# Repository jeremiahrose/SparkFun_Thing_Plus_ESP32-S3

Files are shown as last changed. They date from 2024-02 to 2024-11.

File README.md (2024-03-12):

SparkFun Thing Plus - ESP32-S3
========================================

SparkFun Thing Plus - ESP32-S3 (https://www.sparkfun.com/products/24408)

*[SparkFun Thing Plus - ESP32-S3) (WRL-24408)](https://www.sparkfun.com/products/24408)*

The [SparkFun Thing Plus - ESP32-S3](https://www.sparkfun.com/products/24408) brings a powerful and versatile IoT development platform to the Thing Plus product line. It features the ESP32 WROOM-S3 MINI wireless module from espressif<sup>&trade;</sup>. The ESP32 WROOM-S3 is built around an Xtensa<sup>&reg;</sup> 32-bit LX7 processor with massive processing power that operates at up to 240 MHz. It supports both 2.4 GHz WiFi and Bluetooth<sup>&reg;</sup> 5 (LE) with a built-in PCB antenna. This version of the ESP32-S3 has 4MB Flash memory and 2MB of dynamic/PSRAM and the board also has with a &micro;SD card slot for those who need more storage space.

The module has a large set of peripherals including UART, I<sup>2</sup>C, SPI, LCD control, SDIO host, TWAI<sup>&reg;</sup> controller (compatible
with ISO 11898-1, i.e., CAN Specification 2.), and more. The module allows for customizing which GPIO pins these peripherals operate on though some are limited to specific pins. The ESP32-S3 can run two USB ports simultaneously and can even act as a USB host host device.

The Thing Plus footprint breaks out all of the ESP32-C6's 23 GPIO pins to a pair 0.1"-spaced plated through hole (PTH) headers. The board also has a USB-C connector for primary power and programming, 2-pin JST connector for a LiPo battery (not included), a microSD card slot for expanded storage, and a Qwiic connector to integrate it into SparkFun's [Qwiic ecosystem](https://www.sparkfun.com/qwiic). It also includes a charging circuit and fuel gauge for charging and monitoring an attached LiPo battery. 

Repository Contents
-------------------

* **[/Documents](/Documents/)** - Datasheets, additional product information
* **[/Hardware](/Hardware/)** - Eagle design files (.brd, .sch)
* **[/Firmware](/Firmware/)** - Example sketches demonstrating extra peripherals
* **[/docs](/docs)** - Documentation files for the Thing Plus ESP32-S3 Hookup Guide

Documentation
--------------
* **[Hookup Guide](https://sparkfun.github.io/SparkFun_Thing_Plus_ESP32-S3)** - Hookup guide for the Thing Plus ESP32-S3.

Product Versions
----------------
* [WRL-24408](https://www.sparkfun.com/products/24408) - v1.0, Initial Release

License Information
-------------------

This product is _**open source**_! 

Please review the LICENSE.md file for license information. 

If you have any questions or concerns on licensing, please contact technical support on our [SparkFun forums](https://forum.sparkfun.com/viewforum.php?f=152).

Distributed as-is; no warranty is given.

- Your friends at SparkFun.

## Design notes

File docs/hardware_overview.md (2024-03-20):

---
icon: material/cog
---

Let's take a closer look at the ESP32-S3 module and other hardware present on this Thing Plus board.

## ESP32-S3 Module

This Thing Plus uses the ESP32-S3-MINI1 wireless module from espressif. The ESP32-S3 is built around the extremely powerful Xtensa<sup>&reg;</sup> dual-core 32-bit LX7 microprocessor with a wireless stack that supports 2.4 GHz WiFi and Bluetooth<sup>&reg;</sup> 5 (LE) with an integrated PCB antenna.

<figure markdown>
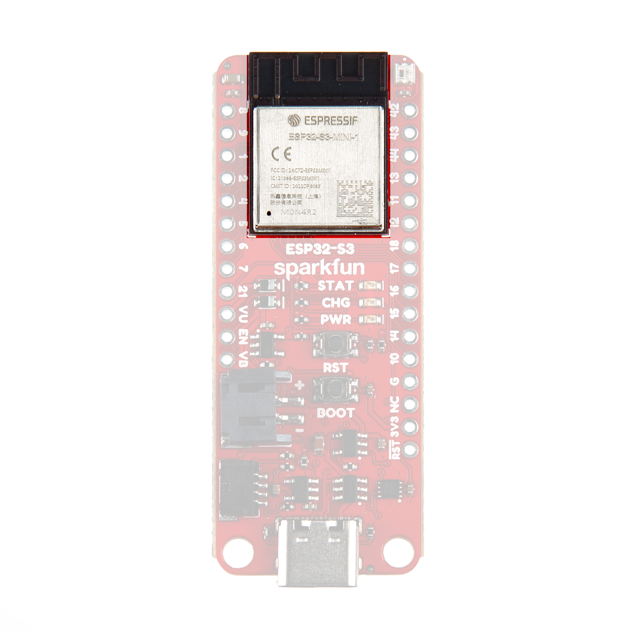
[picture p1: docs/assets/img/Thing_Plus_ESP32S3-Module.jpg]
Photo highlighting ESP32-S3 module.

</figure>

The ESP32-S3-MINI1 offers an impressive peripheral features set including UART, I<sup>2</sup>C, I<sup>2</sup>S, SPI, LCD, Camera Interface, LED PWM, SDIO host, two-wire automotive interface (TWAI<sup>&reg;</sup>) that is compatible with ISO 11898-1/CAN Spec 2.0 and more. This Thing Plus uses the ESP32-S3-MINI1-N4R2 which features 4MB Quad SPI Flash memory and 2MB of PSRAM (Pseudo-static RAM). The ESP32-S3 also has a full-speed USB 2.0 On-The-Go (OTG) interface for USB communication so it does not need any external UART-to-USB conversion.

## Power Components

The Thing Plus ESP32-S3 includes several options for powering including USB-C, LiPo battery with on-board battery charging and monitoring circuits as well as direct power inputs.

<figure markdown>
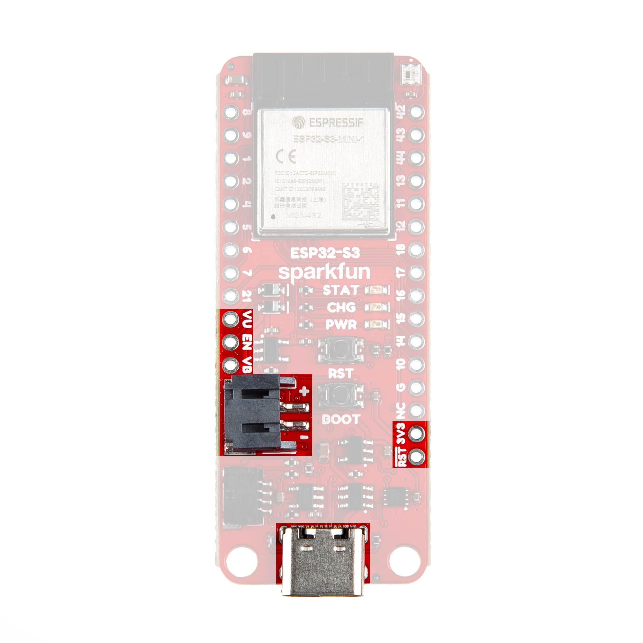
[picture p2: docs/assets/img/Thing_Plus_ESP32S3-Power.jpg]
Photo highlighting power components/pins.

</figure>

### USB-C Connector

The USB-C connector on the board acts as the primary serial interface for the ESP32-S3 module as well as a power input. It connects directly to the ESP32-S3's USB serial converter. The <b>5V</b> USB input voltage is regulated down to <b>3.3V</b> through a voltage regulator with a max current of <b>500mA@3.3V</b>.

### 2-Pin JST Connector, Battery Charger, & Fuel Gauge

The board has a 2-pin JST connector to connect a single-cell Lithium Ion (LiPo) battery for battery-powered applications. It also has an MCP73831 battery charger to charge an attached battery and a MAX17048 fuel gauge to monitor battery voltage levels. The charge rate is set to <b>214mA@3.3V</b>. The MCP73831 receives power from the V_USB line so it only is powered when <b>5V</b> is provided either over USB or the V_USB PTH pin. If applying voltage directly to the V_USB pin make sure it does not exceed <b>5.5V</b>.

The MAX17048's I<sup>2</sup>C lines are pulled up to <b>3.3V_P</b> to allow for customizable power options. Read on below for more information about peripheral power.

## Peripheral Power Control

The board includes a second RT9080 3.3V regulator to control power to the peripheral 3.3V (3.3V_P) rail. This is powered on by default with some options for user control to help conserve power. The RT9080's EN (Enable) pin is tied to ESP45 so users can drive it LOW in their code to disable this line. It also is tied to the main 3.3V rail through the <b>LP_CTL</b> solder jumper so it defaults to powered on. If this solder jumper is opened, it defaults to off when the ESP32-S3 is power-cycled though users can drive the ESP45 pin HIGH in their code to enable the 3.3V_P rail.

## Pinout & Qwiic Connector

Thing Plus boards break out a large number of GPIO and interface pins to a pair of 0.1"-spaced plated through-hole (PTH) headers and also has a Qwiic connector for easy integration into SparkFun's [Qwiic ecosystem](https://www.sparkfun.com/qwiic).

<figure markdown>
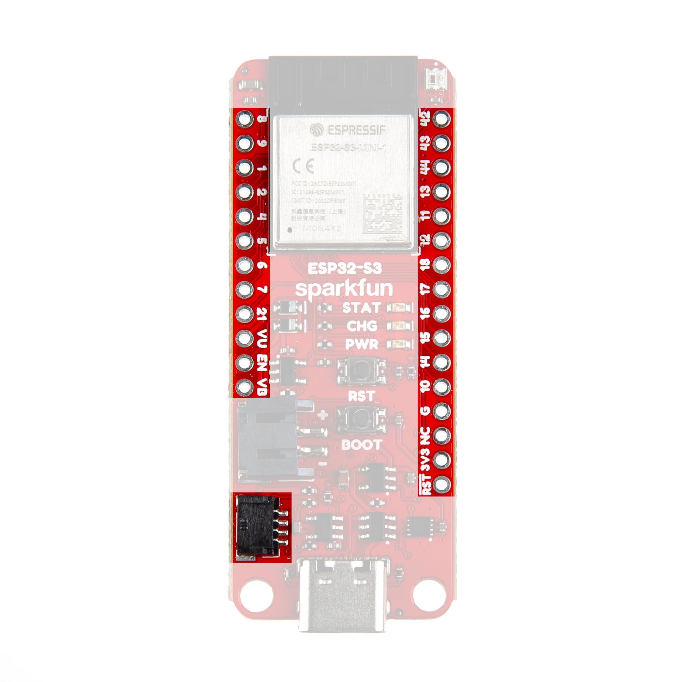
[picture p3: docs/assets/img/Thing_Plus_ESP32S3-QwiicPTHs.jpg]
Photo highlighting pinout and Qwiic connector.

</figure>

### Qwiic Connector

The Qwiic connector is tied to the ESP32-S3's I<sup>2</sup>C bus (IO8/SDA and IO9/SCL). The Qwiic connector provides connections for SDA, SCL, 3.3V, and Ground. Note, the Qwiic connector power and I<sup>2</sup>C pins are tied to 3.3V_P and are powered by default but if the peripheral power control circuit is adjusted as covered above, it will not function properly without enabling 3.3V_P through code.

### PTH Headers

The Thing Plus's pair of PTH headers break out a selection of 21 GPIO pins from the ESP32-S3 along with PTH connections to USB voltage (5V), regulated 3.3V, battery voltage, ESP32 reset signal, and the voltage regulator Enable pin.

<figure markdown>
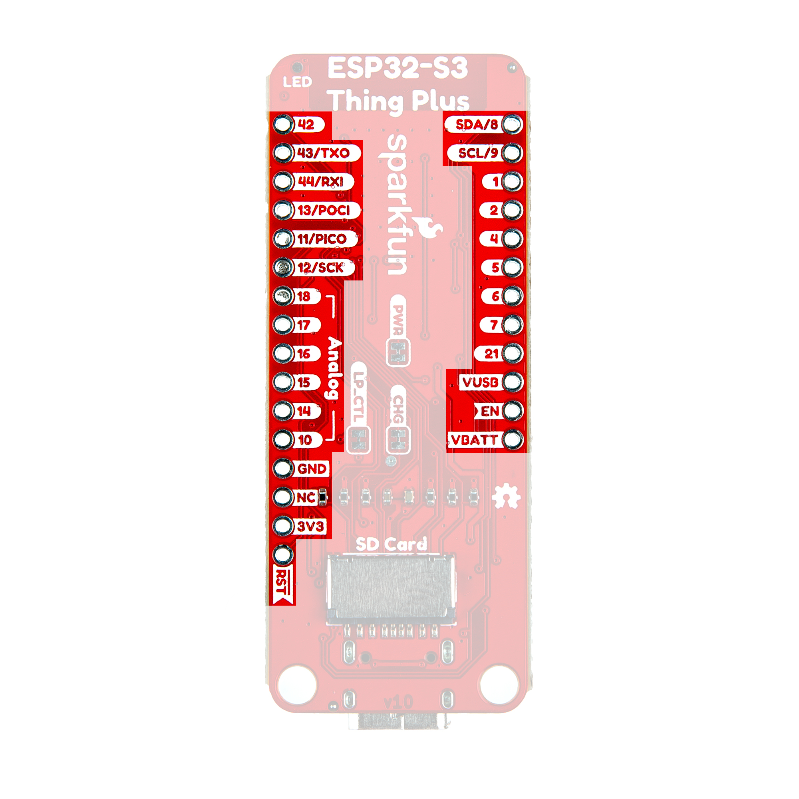
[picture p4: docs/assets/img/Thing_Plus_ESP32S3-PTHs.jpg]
Photo highlighting PTH pinout.

</figure>

Nearly all of the GPIO pins can function in multiple configurations though some of them have more capabilities than others and some are limited to fewer functions. Pins labeled 10, 14, 15, 16, 17, and 18 are all analog capable and also work as capacitive touch inputs. The pins labeled for UART (RX/TX), I<sup>2</sup>C (SDA/SCL), and SPI (POCI, PICO, & SCK) work primarily for their labeled functions but can be altered for other uses. Refer to the [datasheet](./assets/component_documentation/esp32-s3-mini-1_mini-1u_datasheet_en.pdf) datasheet for complete information on the pin functionality.

## &micro;SD Card Slot

The board has a &micro;SD card slot that connects to the ESP32-S3's SDIO-4 pins. It is a fricton-fit connector so no "clicking" and "unclicking" is necessary. Just plug it in nice and snug. 

<figure markdown>
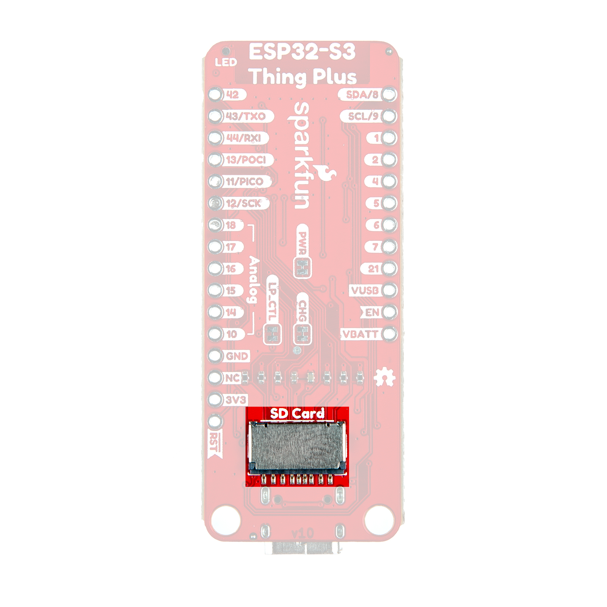
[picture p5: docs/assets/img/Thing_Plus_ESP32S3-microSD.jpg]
Photo highlighting microSD card slot.

</figure>

We chose to connect the SD card to the SDIO interface instead of the dedicated SPI bus as we found it to be reliably faster for read/write speeds averaging roughly 2-3MB/s (read) and ~5-7MB/s (write) though speeds vary depending on the card used. One thing to note about this connector is the SD Card Detect pin is pulled to Ground (LOW) with no card present and shorts to 3.3V (HIGH) with a card inserted. Read on to the "Arduino Examples" section for an example of how to monitor and read this pin.

## Buttons

There are two buttons on the board labeled <b>RESET</b> and <b>BOOT</b>. The RESET button is tied to the ESP32-S3's Enable (EN) pin and resets the module when pressed. The BOOT button puts the ESP32-S3 into bootloader mode when held down during power on or reset.

<figure markdown>
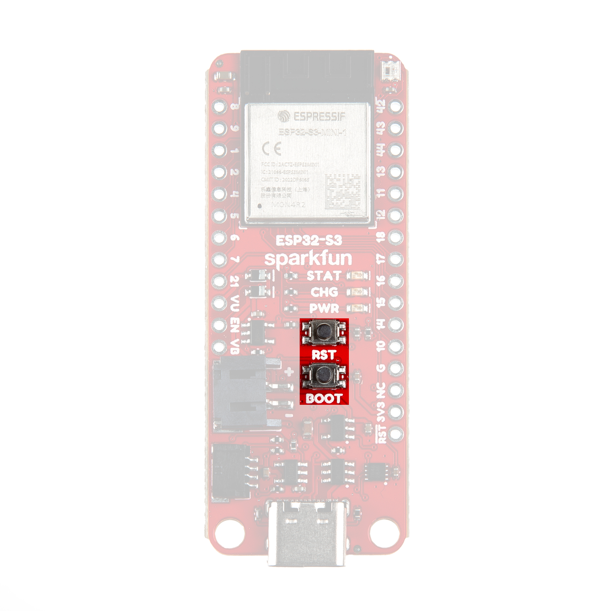
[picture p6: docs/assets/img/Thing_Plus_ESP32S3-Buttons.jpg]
Photo highlighting buttons.

</figure>

## LEDs

This Thing Plus has three standard LEDs labeled <b>PWR</b>, <b>CHG</b>, <b>STAT</b>, and a WS2812 RGB LED next to the ESP32-S3 module on the top of the board. The red Power (PWR) LED indicates whenever the <b>3.3V</b> circuit is powered. The yellow Charge (CHG) LED indicates whenever the MCP73831 is charging a connected LiPo battery. The green Status (STAT) LED is tied to IO0. The WS2812 RGB LED connects the LED's Data In signal to IO46.

<figure markdown>
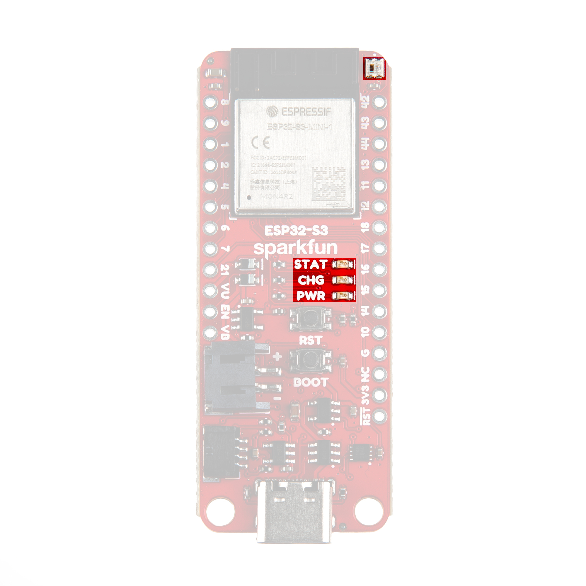
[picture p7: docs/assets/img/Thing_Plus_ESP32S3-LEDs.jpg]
Photo highlighting LEDs.

</figure>

## Solder Jumpers

The board has three solder jumpers labeled <b>PWR</b>, <b>CHG</b>, and <b>LP_CTL</b>. The <b>PWR</b> jumper completes the circuit for the Power LED and is CLOSED by default. Open it to disable the Power LED. The <b>CHG</b> jumper completes the circuit for the Charge LED and is CLOSED by default. Open the solder jumper to disable the Charge LED.

<figure markdown>
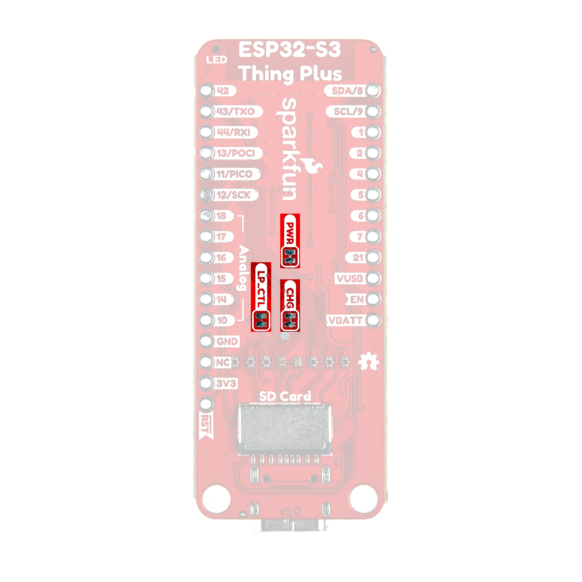
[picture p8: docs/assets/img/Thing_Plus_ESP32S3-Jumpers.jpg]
Photo highlighting solder jumpers.

</figure>

The <b>LP_CTL</b> jumper controls how the Low Power and Peripherals power works. It is CLOSED by default to pull the power the RT9080 3.3V regulator's enable pin HIGH to enable peripheral power on the <b>3.3V_P</b> rail. When opened, the regulator's enable pin connects directly to ESP32 IO45 for users to control manually. Refer to "Peripheral Power Control" above for more information.

## Board Dimensions

This board matches the Thing Plus footprint and measures 2.30" x 0.90" (58.42mm x 22.86mm) with four mounting holes that fit a [4-40 screw](https://www.sparkfun.com/products/10453) though the top two mounting holes are slightly obstructed by the ESP32-S3 module so using those can be a bit troublesome.

<figure markdown>
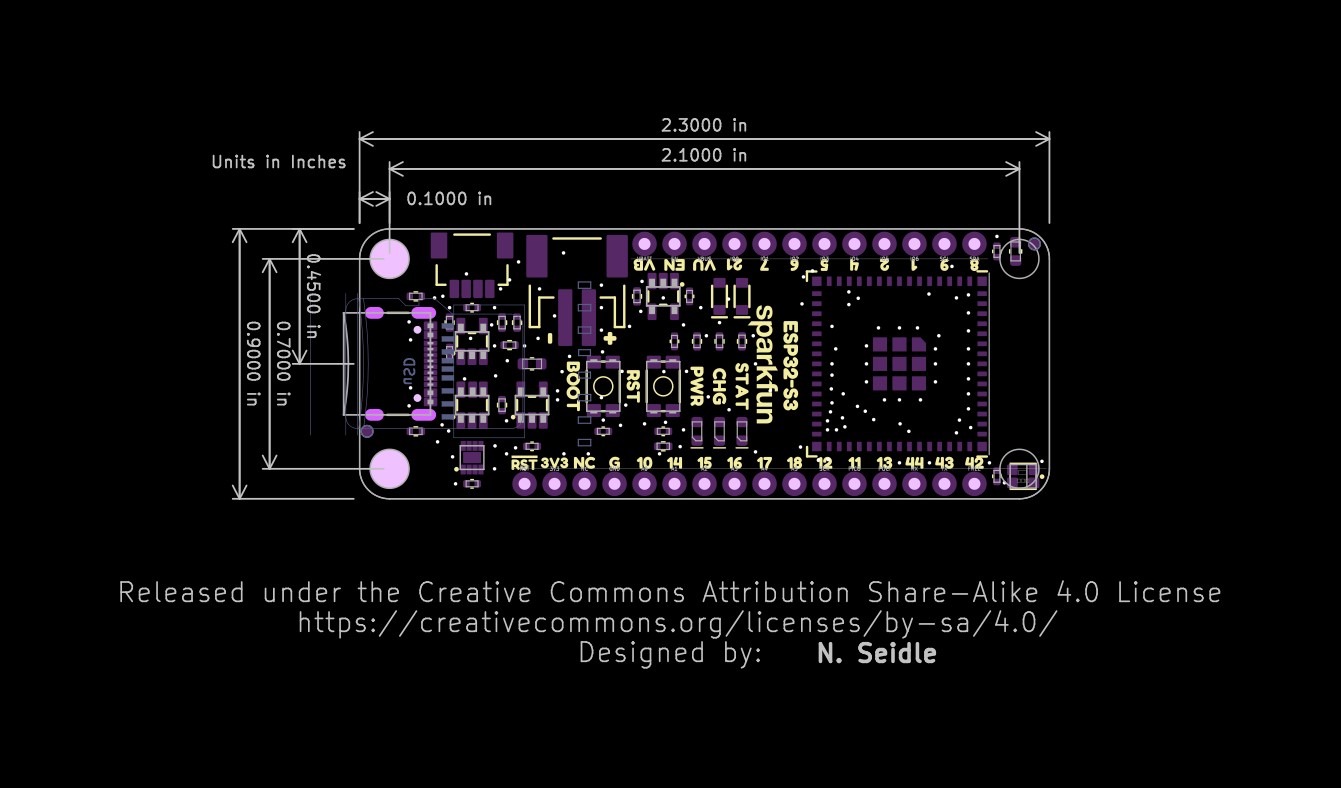
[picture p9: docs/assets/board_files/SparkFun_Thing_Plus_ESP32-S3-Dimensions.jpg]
Board dimensions.

</figure>

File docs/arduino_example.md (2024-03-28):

---
icon: simple/arduino
---

Now that we've installed the espressif boards package in Arduino, it's time to upload our first sketch to make sure everything installed and is working properly. 

## Thing Plus ESP32-S3 Github Repository

We've written a few example sketches for this specific board that live in the [Github repository](https://github.com/sparkfun/SparkFun_Thing_Plus_ESP32-S3) that we recommend taking a look at as they demonstrate some important hardware use cases. You can download it from the link above or you can get a ZIP of the library by clicking the button below:

<center>
[SparkFun Thing Plus - ESP32-S3 Github Repository (ZIP)](https://github.com/sparkfun/SparkFun_Thing_Plus_ESP32-S3/archive/refs/heads/main.zip){ .md-button .md-button--primary }    
</center>

!!! important "esptool Upload Errors"

    Some users may run into this upload error related to esptool:

    esptool.py v4.5.1
    Serial port COM33
    Connecting....

    A serial exception error occurred: Write timeout
    Note: This error originates from pySerial. It is likely not a problem with esptool, but with the hardware connection or drivers.
    For troubleshooting steps visit: https://docs.espressif.com/projects/esptool/en/latest/troubleshooting.html
    the selected serial port For troubleshooting steps visit: https://docs.espressif.com/projects/esptool/en/latest/troubleshooting.html
    does not exist or your board is not connected

    This error means the board is not entering ROM bootloader mode automatically, causing the upload to hang and fail. We found this relates specifically to esptool.py v4.5.1 in the current stable release of the ESP32 Boards Package (2.0.11). Users can work around this error with one of the following three fixes: 
    
    1. Use the alpha release (3.0.0 alpha3) of the ESP32 Boards Package. This release updates to esptool.py v4.6.
    2. Download the latest release of esptool.py from the [GitHub repository](https://github.com/espressif/esptool/releases) releases and then manually replace it in the espressif boards package folder. 
    3. If you want to keep using the current full release and encounter this error, force the board to enter the bootloader by holding the BOOT button down, clicking the RESET button, and then releasing the BOOT button.

## Board Settings

As mentioned in the previous section, the Thing Plus ESP32-S3 is not currently included in the ESP32 Boards Package so we recommend selecting "ESP32S3 Dev Module" for your board with the following settings:

* USB Mode: Hardware CDC and JTAG
* USB CDC on Boot: Enabled
* Upload Mode: UART0 / Hardware CDC
* PSRAM: QSPI PSRAM

This does require some manual definition/setup for pins in the code which the examples below demonstrate for some of the main peripheral components (Qwiic, &micro;SD card, etc.). 

## RGB LED

This example uses the FastLED library to cycle the RGB LED on the Thing Plus through a rainbow. Open the code from your downloaded copy of the GitHub repository or copy the code below into a blank sketch. Make sure the FastLED Library is installed, select the board (ESP32S3 Dev Module) and the Port, and click the "Upload" button.  

??? "RGB LED Example"
    ```

    --8<-- "https://raw.githubusercontent.com/sparkfun/SparkFun_Thing_Plus_ESP32-S3/main/Firmware/RGB_LED/RGB_LED.ino"
    ```

## I<sup>2</sup>C Scanner Power Control

This example shows how to toggle the peripheral power voltage supply on and off as well as scan for any I<sup>2</sup>C devices connected to the I<sup>2</sup>C bus/Qwiic connector. After uploading, open the [serial monitor](https://learn.sparkfun.com/tutorials/terminal-basics/arduino-serial-monitor-windows-mac-linux) with the baud set to **115200** and you should see a serial printout of the Fuel Gauge at 0x32 as well as any other devices connected to the Qwiic connector like the screenshot below shows. If you have a Qwiic board plugged in you should see the power LED on it blinking every second as the bus is powered on and off.

??? "I2C Scanner Power Control Example"
    ```

    --8<-- "https://raw.githubusercontent.com/sparkfun/SparkFun_Thing_Plus_ESP32-S3/main/Firmware/I2C_Scanner_PowerControl/I2C_Scanner_PowerControl.ino"
    ```

<figure markdown>
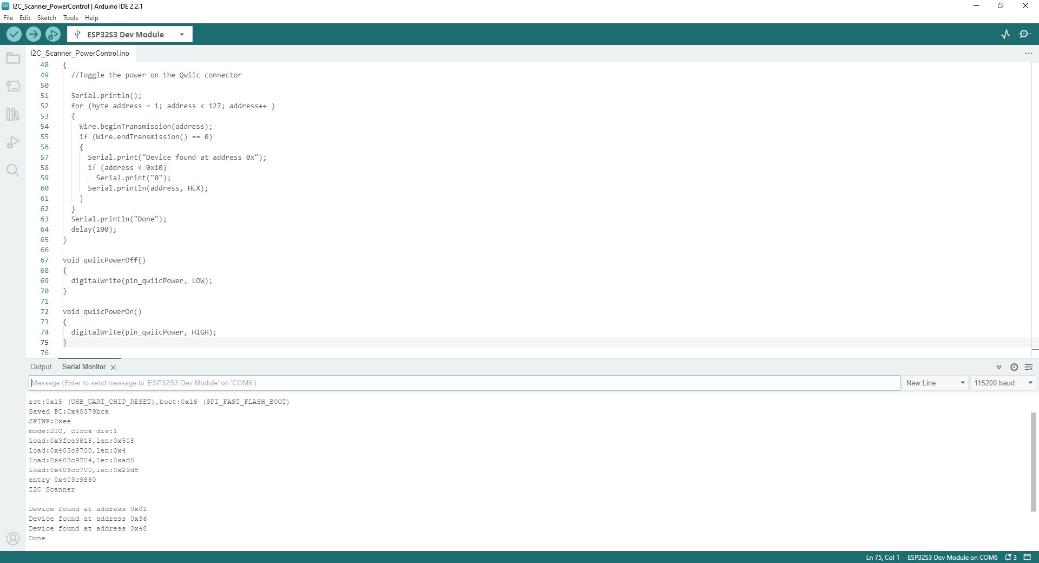
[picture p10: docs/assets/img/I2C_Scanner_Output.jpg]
Serial printout of I2C scan.

</figure>

## SD Card Detect

The SD Card Detect example is a simple example that monitors the card detect pin on the &micro;SD card slot. As mentioned in the Hardware Overview section, the card detect switch is normally open and closed with a card inserted so the switch goes to VDD (3.3V). This requires us to set up an internal pull-down for card detection to work properly. 

After uploading, you can open the serial monitor with the baud set to **115200** and it should print out either "Card Inserted" or "No SD Card" depending on whether or not a &micro;SD card is present.

??? "SD Card Detect Example"
    ```

    --8<-- "https://raw.githubusercontent.com/sparkfun/SparkFun_Thing_Plus_ESP32-S3/main/Firmware/SD_Card_Detect/SD_Card_Detect.ino"
    ```

## PSRAM Test

This example demonstrates how to enable and use PSRAM for RAM requests above a 1,000 byte threshold. The setup initializes PSRAM and prints out whether or not this was successful and then prints out available PSRAM space.

??? "PSRAM Test Example"
    ```

    --8<-- "https://raw.githubusercontent.com/sparkfun/SparkFun_Thing_Plus_ESP32-S3/main/Firmware/PSRAM_Test/PSRAM_Test.ino"
    ```

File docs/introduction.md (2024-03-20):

---
icon: material/book-open-page-variant
---

<div class="grid cards desc" markdown>

-    <a href="https://www.sparkfun.com/products/24408">
    **SparkFun Thing Plus - ESP32-S3**<br>
    **SKU:** DEV-24408

    ---

    <figure markdown>
    Product Thumbnail
    </figure></a>

-    The SparkFun Thing Plus - ESP32-S3 features the powerful and versatile ESP32-S3 from espressif<sup>&trade;</sup>. The ESP32-S3  It includes a LiPo battery charger and fuel gauge, &micro;SD card slot, an addressable LED and more. The Thing Plus footprint breaks out all of the ESP32-S3's 23 GPIO pins to 0.1"-spaced PTH headers. The board also has a USB-C connector for primary power and programming, 2-pin JST connector for a LiPo battery, and a Qwiic connector to integrate it into SparkFun's [Qwiic ecosystem](https://www.sparkfun.com/qwiic).

    The ESP32 WROOM-S3 is built around an Xtensa<sup>&reg;</sup> 32-bit LX7 processor with massive processing power that operates at up to 240 MHz. It supports both 2.4 GHz WiFi and Bluetooth<sup>&reg;</sup> 5 (LE) with a built-in PCB antenna. This version of the ESP32-S3 has 4MB Flash memory and 2MB of dynamic/PSRAM and the board also has a &micro;SD card slot for those who need more storage space.

    The module has a host of peripherals that can be tied to nearly any GPIO pin including UART, I<sup>2</sup>C, SPI, LCD control, SDIO host, TWAI<sup>&reg;</sup> controller (compatible with ISO 11898-1, i.e., CAN Specification 2.), and more. The ESP32-S3 can run two USB ports simultaneously and can act as a USB host.

    <center>
    [Purchase from SparkFun :fontawesome-solid-cart-plus:{ .heart }](https://www.sparkfun.com/products/24408){ .md-button .md-button--primary }
    </center>

</div>

## Required Materials

To follow along with this guide you will need at least one USB-C cable to connect the Thing Plus to your computer: 

<div class="grid cards" markdown>

-   <a href="https://www.sparkfun.com/products/14743">

    <figure markdown>
    USB 3.1 Cable A to C - 3 Foot
    </figure>
    </a>
    ---
    <a href="https://www.sparkfun.com/products/14743">
    **USB 3.1 Cable A to C - 3 Foot**<br>
    CAB-14743
    </a>

-   <a href="https://www.sparkfun.com/products/15424">
    
    <figure markdown>
    Reversible USB A to C Cable - 2m
    </figure>
    </a>
    ---
    <a href="https://www.sparkfun.com/products/15424">
    **Reversible USB A to C Cable - 2m**<br>
    CAB-15424
    </a>
</div>

You may also want to get a Qwiic cable or kit to connect the Thing Plus - ESP32-C6 to other Qwiic devices:

<div class="grid cards" markdown>

-   <a href="https://www.sparkfun.com/products/17260">
    
    <figure markdown>
    Qwiic Cable - 50mm
    </figure>
    </a>
    ---
    <a href="https://www.sparkfun.com/products/17260">
    **Flexible Qwiic Cable - 50mm**<br>
    PRT-17260
    </a>

-   <a href="https://www.sparkfun.com/products/17257">
    
    <figure markdown>
    Flexible Qwiic Cable - 500mm
    </figure>
    </a>
    ---
    <a href="https://www.sparkfun.com/products/17257">
    **Flexible Qwiic Cable - 500mm**<br>
    PRT-17257
    </a>

-   <a href="https://www.sparkfun.com/products/17261">

    <figure markdown>
    Flexible Qwiic Cable - Female Jumper (4-pin)
    </figure>
    </a>
    ---
    <a href="https://www.sparkfun.com/products/17261">**Flexible Qwiic Cable - Female Jumper (4-pin)**<br>
    CAB-17261
    </a>

-   <a href="https://www.sparkfun.com/products/15081">

    <figure markdown>
    SparkFun Qwiic Cable Kit
    </figure>
    </a>
    ---
    <a href="https://www.sparkfun.com/products/15081">
    **SparkFun Qwiic Cable Kit**<br>
    PRT-15081
    </a>

</div>

## Optional Materials

The Thing Plus - ESP32-C6 includes a 2-pin JST connector and integrated charging circuit for an attached single-cell LiPo battery. Below are a few options we recommend for battery-powered applications:

<div class="grid cards" markdown align="center">

-   <a href="https://www.sparkfun.com/products/18286">

    <figure markdown>
    Lithium Ion Battery - 1250mAh (IEC62133 Certified)
    </figure>
    </a>
    ---
    <a href="https://www.sparkfun.com/products/18286">
    **Lithium Ion Battery - 1250mAh (IEC62133 Certified)**<br>
    PRT-18286
    </a>

-   <a href="https://www.sparkfun.com/products/13855">

    <figure markdown>
    Lithium Ion Battery - 2Ah
    </figure>
    </a>
    ---
    <a href="https://www.sparkfun.com/products/13855">
    **Lithium Ion Battery - 2Ah**<br>
    PRT-13855
    </a>

-   <a href="https://www.sparkfun.com/products/13851">

    <figure markdown>
    Lithium Ion Battery - 400mAh
    </figure>
    </a>
    ---
    <a href="https://www.sparkfun.com/products/13851">
    **Lithium Ion Battery - 400mAh**<br>
    PRT-13851
    </a>

-   <a href="https://www.sparkfun.com/products/13854">

    <figure markdown>
    Lithium Ion Battery - 850mAh
    </figure>
    </a>
    ---
    <a href="https://www.sparkfun.com/products/13854">
    **Lithium Ion Battery - 850mAh**<br>
    PRT-13854
    </a>
</div>

If you prefer a soldered connection or want to modify the solder jumpers on this board, you may need some of the products listed below:

<div class="grid cards" markdown align="center">

-   <a href="https://www.sparkfun.com/products/116">

    <figure markdown>
    SparkFun Qwiic Shield for Thing Plus
    </figure>
    </a>
    ---
    <a href="https://www.sparkfun.com/products/16790">
    **SparkFun Qwiic Shield for Thing Plus**<br>
    DEV-16790
    </a>

-   <a href="https://www.sparkfun.com/products/9507">
    
    <figure markdown>
    PINECIL - Smart Mini Portable Soldering Iron
    </figure>
    </a>
    ---
    <a href="https://www.sparkfun.com/products/23913">
    **PINECIL - Smart Mini Portable Soldering Iron**<br>
    TOL-23913
    </a>

-   <a href="https://www.sparkfun.com/products/9200">
    
    <figure markdown>
    Hobby Knife
    </figure>
    </a>
    ---
    <a href="https://www.sparkfun.com/products/9200">
    **Hobby Knife**<br>
    TOL-09200
    </a>

-   <a href="https://www.sparkfun.com/products/14579">

    <figure markdown>
    Chip Quik No-Clean Flux Pen - 10mL
    </figure>
    </a>
    ---
    <a href="https://www.sparkfun.com/products/14579">**Chip Quik No-Clean Flux Pen - 10mL**<br>
    CAB-14579
    </a>
</div>

## Suggested Reading

We designed this board for integration into SparkFun's Qwiic connect system.  Click on the banner below to learn more about the [SparkFun Qwiic Connect System](https://www.sparkfun.com/qwiic).

<div style="text-align: center">
<table>
  <tr>
   <td>
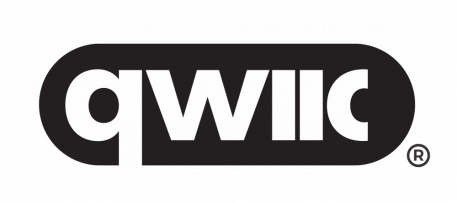
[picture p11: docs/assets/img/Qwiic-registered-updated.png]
Qwiic Connect System Click to learn more about the Qwiic Connect System!
   <div style="text-align: center"></div>
   </td>
  </tr>
  <tr>
    <td><div style="text-align: center"><i><a href="https://www.sparkfun.com/qwiic">Qwiic Connect System</a></i></div></td>
  </tr>
</table>
</div>

Before getting started with this Hookup Guide, you may want to read through the tutorials below if you are not familiar with the concepts covered in them or want a refresher. If you are using either of the Qwiic Shields linked above, we recommend reading through their respective Hookup Guides before continuing with this tutorial:

<div class="grid cards hide col-4" markdown align="center">

-   <a href="https://learn.sparkfun.com/tutorials/8">
    <figure markdown>
    Serial Communication
    </figure>
    </a>
    <a href="https://learn.sparkfun.com/tutorials/8">**Serial Communication**
    </a>

-   <a href="https://learn.sparkfun.com/tutorials/82">
    <figure markdown>
    I2C
    </figure>
    </a>
    <a href="https://learn.sparkfun.com/tutorials/82">**I2C**
    </a>

-   <a href="https://learn.sparkfun.com/tutorials/62">
    <figure markdown>
    Logic Levels
    </figure>
    </a>
    <a href="https://learn.sparkfun.com/tutorials/62">**Logic Levels**
    </a>

-   <a href="https://learn.sparkfun.com/tutorials/61">
    <figure markdown>
    Installing Arduino IDE
    </figure>
    </a>
    <a href="https://learn.sparkfun.com/tutorials/61">**Installing Arduino IDE**
    </a>

-   <a href="https://learn.sparkfun.com/tutorials/15">
    <figure markdown>
    Installing an Arduino Library
    </figure>
    </a>
    <a href="https://learn.sparkfun.com/tutorials/15">**Installing an Arduino Library**
    </a>

-   <a href="https://learn.sparkfun.com/tutorials/112">
    <figure markdown>
    Serial Terminal Basics
    </figure>
    </a>
    <a href="https://learn.sparkfun.com/tutorials/112">**Serial Terminal Basics**
    </a>

-   <a href="https://learn.sparkfun.com/tutorials/1107">
    <figure markdown>
    SparkFun Qwiic Shield for Thing Plus Hookup Guide
    </figure>
    </a>
    <a href="https://learn.sparkfun.com/tutorials/1107">**SparkFun Qwiic Shield for Thing Plus Hookup Guide**
    </a>

-   <a href="https://learn.sparkfun.com/tutorials/664">
    <figure markdown>
    How to Work with Jumper Pads and PCB Traces
    </figure>
    </a>
    <a href="https://learn.sparkfun.com/tutorials/664">**How to Work with Jumper Pads and PCB Traces**
    </a>
</div>

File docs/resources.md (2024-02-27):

For more information about the Thing Plus - ESP32-S3, check out the resources below:

* [Schematic](./assets/board_files/SparkFun_Thing_Plus_ESP32-S3.pdf)
* [KiCad Board Files](./assets/board_files/SparkFun_Thing_Plus_ESP32-S3.zip)
* [Board Dimensions](./assets/board_files/SparkFun_Thing_Plus_ESP32-S3-Dimensions.jpg)
* [Datasheet](./assets/component_documentation/esp32-s3-mini-1_mini-1u_datasheet_en.pdf) (ESP32-S3-MINI1)
* [GitHub Repository](https://github.com/sparkfun/SparkFun_Thing_Plus_ESP32-S3)
* [Thing Plus Info Page](https://www.sparkfun.com/thing_plus)
* [Qwiic Info Page](https://www.sparkfun.com/qwiic)

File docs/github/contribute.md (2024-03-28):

# Help Improve the Experience!
Spot an improvement opportunity? Feel free to contribute to our open-source design and documentation. 

## Enhance our Documentation
All of this documentation can be modified by you! Please help us make it better.

* These pages are contained in the [`docs` folder](https://github.com/sparkfun/SparkFun_Thing_Plus_ESP32-S3/tree/main/docs) of the [SparkFun Thing Plus - ESP32-S3](https://github.com/sparkfun/SparkFun_Thing_Plus_ESP32-S3) repository.

### Submit a Correction
1. Fork this repo
2. Add your corrections or improvements to the markdown file
3. File a pull request with your changes, and enjoy making the ~~words~~ ~~worlds~~ world a better place.
	* Once received, the documentation specialist will automatically be notified.
	* We will review your suggested improvements to make sure they are correct and fit within our documentation standards.

## Upgrade our Hardware Design
All of our designs are open-source! Please help us make it better.

* Our board design files are contained in the [`Hardware` folder](https://github.com/sparkfun/SparkFun_Thing_Plus_ESP32-S3/tree/main/Hardware) of the [SparkFun Thing Plus - ESP32-S3](https://github.com/sparkfun/SparkFun_Thing_Plus_ESP32-S3) repository.

### Submit a Design Improvement
1. Fork this repo
2. Add your design modifications
3. File a pull request with your changes, and enjoy making the world a better place.
	* Once received, the engineer in charge of the original design will automatically be notified.
	* We will review your suggested upgrades, if they are within our board design standards and meet our product design requirements, we will flag these changes for our next board revision.
	
	!!! note
		Please note, that even if your suggestion is accepted, these changes may not be immediate. We may have to cycle through our current product inventory first.

## Contributors
Let's provide some recognition to those who have contributed to this project!

GitHub Contributors Image
<br>


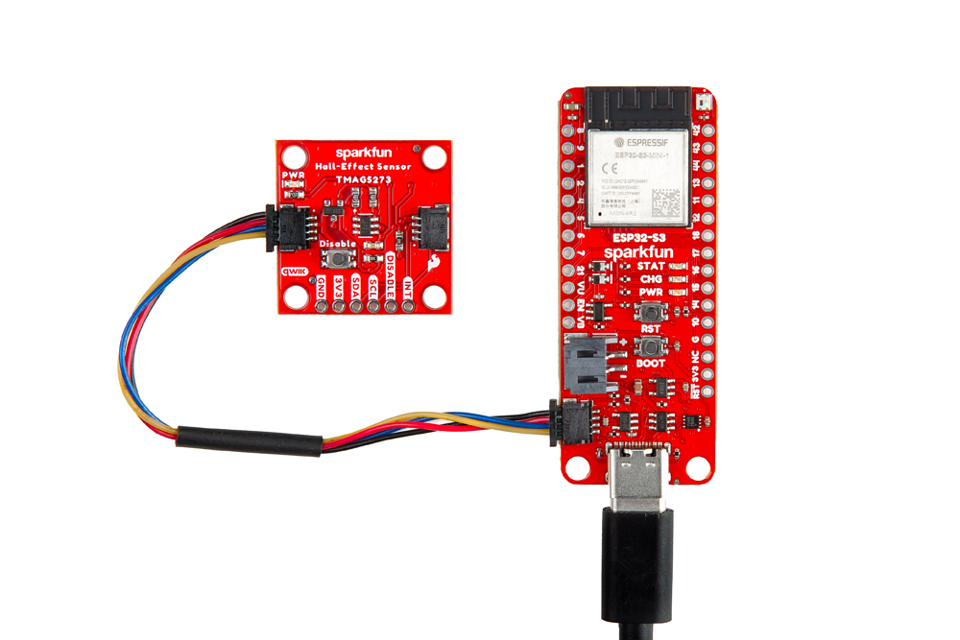
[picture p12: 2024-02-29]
docs/assets/img/WRL-24408-ESP-32-S3-Action-2.jpg

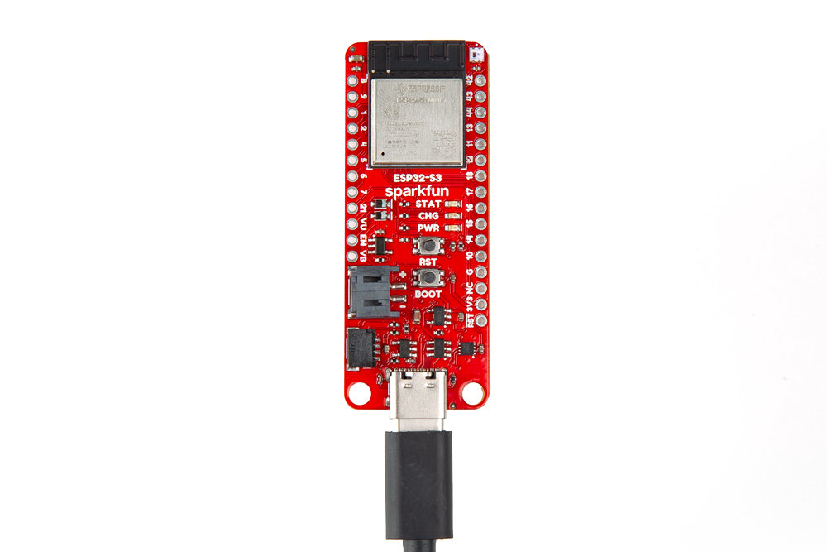
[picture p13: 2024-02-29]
docs/assets/img/WRL-24408-ESP-32-S3-Action-4.jpg

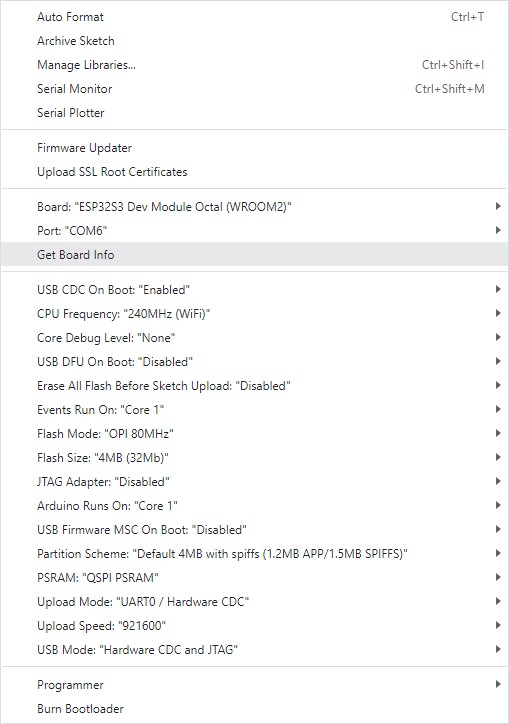
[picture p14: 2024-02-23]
docs/assets/img/Arduino_board_settings.jpg

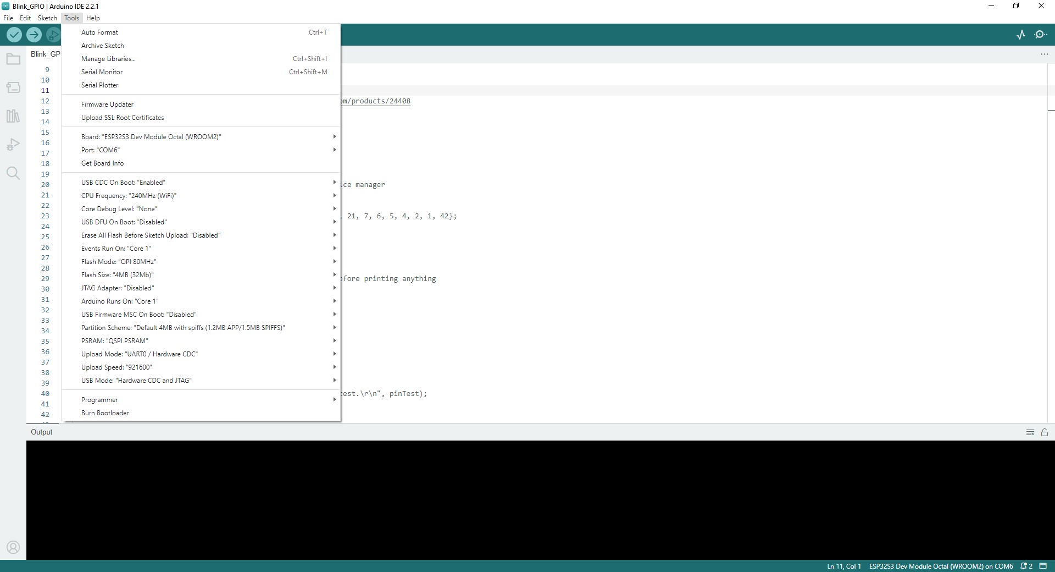
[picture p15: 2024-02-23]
docs/assets/img/Arduino_board_settings1.jpg

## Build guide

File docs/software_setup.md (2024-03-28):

---
icon: simple/arduino
---

!!! attention
	If this is your first time using Arduino, please read through our tutorial on [installing the Arduino IDE](https://learn.sparkfun.com/tutorials/installing-arduino-ide). If you have not installed an Arduino library before, we recommend you check out our [installation guide](https://learn.sparkfun.com/tutorials/installing-an-arduino-library).

With the ESP32-S3 Thing Plus connected to our computer, it's time to set up the boards package in Arduino.

## Installing espressif Arduino Boards
    
To install the ESP32 boards package, open the Preferences menu by navigating to <b>File</b> > <b>Preferences</b>. Look at the bottom of the Preferences menu for "Additional boards manager URLS" and then copy this JSON link into that field:

<code>
    https://espressif.github.io/arduino-esp32/package_esp32_dev_index.json
</code>

Click "Ok" and then open the *Boards Manager* tool, search for "espressif ESP32" and install the latest alpha release (3.0.0-alpha2 or later). This install process may take some time so feel free to step away while it downloads and installs.

## Optional Arduino Libraries

Most of the examples we cover in the next section use existing libraries included with the ESP32 Arduino core but the RGB LED example uses the FastLED library so you'll need it installed to follow along with that example. Navigate to the "Libraries" menu on the left side of the screen, search for "FastLED", and install the latest version. If you prefer to manually install the library, you can download a ZIP of the library by clicking the button below:

<center>
[FastLED Arduino Library](https://github.com/FastLED/FastLED/archive/refs/heads/master.zip){ .md-button .md-button--primary }   
</center>

## espressif IDF

Users who prefer to use espressif's development toolkit, espressif IDF, can get started by following their instructions [here](https://www.espressif.com/en/products/sdks/esp-idf) and  ESP32-S3 specific documentation [here](https://docs.espressif.com/projects/esp-idf/en/stable/esp32S3/index.html).

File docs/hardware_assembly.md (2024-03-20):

---
icon: material/cog
---

Now that we're familiar with the hardware on this Thing Plus board, it's time to connect it to our computer or battery power.

## Basic USB Assembly

Basic assembly of the Thing Plus ESP32-S3 only requires a USB-C cable connecting the board to a computer. Just plug the cable into the USB-C connector and move on to the Software Setup section. When powered up for the first time, the RGB LED on the "top-right" of the board should be cycling through a rainbow color similar to the video below:

<figure markdown>
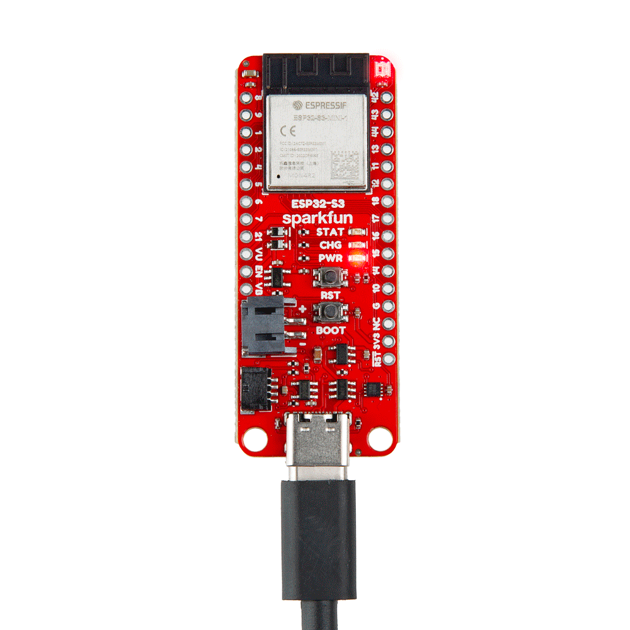
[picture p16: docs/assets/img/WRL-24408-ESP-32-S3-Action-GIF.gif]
Short video showing RGB led cycling.

</figure>

!!! note
    Your computer may not recognize the board as a known USB device if you have not installed the espressif boards package in Arduino and/or installed the espressif IDF.

## Battery Assembly

If you prefer a battery-powered application, plug a single-cell LiPo battery into the 2-pin JST connector on the underside of the board like the photo below. Remember, the MCP73831 only charges the battery when V_USB has voltage present either from the USB-C connector or through the V_USB PTH pin.

For tips on the proper use of a LiPo battery and the 2-pin JST connector, please read through our [Single Cell LiPo Battery Care](https://learn.sparkfun.com/tutorials/single-cell-lipo-battery-care) tutorial.

## Soldered Assembly

Those who prefer a traditional soldered assembly should solder wires or header pins to the PTH header on the side of the board. If you're not familiar with through-hole soldering or would like a refresher, take a look at our Through-Hole Soldering Tutorial:

<div class="grid cards" markdown align="center">

-   <a href="https://learn.sparkfun.com/tutorials/5">
    <figure markdown>
    How to Solder: Through-Hole Soldering
    </figure>
    </a>
    <a href="https://learn.sparkfun.com/tutorials/5">**How to Solder: Through-Hole Soldering**
    </a>

</div>

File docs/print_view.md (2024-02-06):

---
hide:
  - navigation
  - toc
icon: fontawesome/solid/scroll
---

# Introduction
--8<-- "./docs/introduction.md:5"

# Hardware Overview
--8<-- "./docs/hardware_overview.md:5"

# Hardware Assembly
--8<-- "./docs/hardware_assembly.md:5"

## Software Setup
--8<-- "./docs/software_setup.md:5"

## Arduino Examples
--8<-- "./docs/arduino_example.md"

# Troubleshooting Tips
--8<-- "./docs/troubleshooting.md:5"

# Resources:
--8<-- "./docs/resources.md"

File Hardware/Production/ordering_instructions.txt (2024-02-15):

Ordering Instructions:
Panel dimensions: 106.64 x 205.20 mm.
Controlled Impedance: JLC7628
Material: TG155
Solder Mask: Red
Silkscreen: White
Layers: 4
Finish: HASL Lead-Free
Thickness: 1.6mm
Outer Copper Weight: 1oz
Minimum track width: 0.15mm (6.00mil)
Minimum via drill: 0.30mm (11.81mil)

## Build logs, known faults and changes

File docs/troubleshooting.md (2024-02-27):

## esptool Upload Error

Some users may run into this upload error related to esptool:

esptool.py v4.5.1
Serial port COM33
Connecting....

A serial exception error occurred: Write timeout
Note: This error originates from pySerial. It is likely not a problem with esptool, but with the hardware connection or drivers.
For troubleshooting steps visit: https://docs.espressif.com/projects/esptool/en/latest/troubleshooting.html
the selected serial port For troubleshooting steps visit: https://docs.espressif.com/projects/esptool/en/latest/troubleshooting.html
does not exist or your board is not connected

This error means the board is not entering ROM bootloader mode automatically, causing the upload to hang and fail. We found this relates specifically to esptool.py v4.5.1 in the current stable release of the ESP32 Boards Package (2.0.11). Users can work around this error with one of the following three fixes: 
    
1. Use the alpha release (3.0.0 alpha3) of the ESP32 Boards Package. This release updates to esptool.py v4.6.
2. Download the latest release of esptool.py from the [GitHub repository](https://github.com/espressif/esptool/releases) releases and then manually replace it in the espressif boards package folder. 
3. If you want to keep using the current full release and encounter this error, force the board to enter the bootloader by holding the BOOT button down, clicking the RESET button, and then releasing the BOOT button.

### Digital Reset

Some users may run into an issue when uploading completes where the board does not digitally reset properly. If you notice your code is not running after upload finishes, just press the RESET button on the board and it should start running.

## General Troubleshooting

!!! warning "Need Help?"
    If you need technical assistance or more information on a product that is not working as you expected, we recommend heading on over to the [SparkFun Technical Assistance](https://www.sparkfun.com/technical_assistanc) page for some initial troubleshooting.

    <center>
    [SparkFun Technical Assistance Page](https://www.sparkfun.com/technical_assistance){ .md-button .md-button--primary }
    </center>
    
    If you can't find what you need there, the [SparkFun Forums](https://forum.sparkfun.com/index.php) is a great place to search product forums and ask questions.
    
    !!! info "Account Registration Required"
        If this is your first visit to our forum, you'll need to create a [Forum Account](https://forum.sparkfun.com/ucp.php?mode=register) to post questions.

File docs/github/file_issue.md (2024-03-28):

# Did we make a mistake?

Spot something wrong? Please let us know. 

!!! attention
	This is not where customers should seek assistance on a product. If you require technical assistance or have questions about a product that is not working as expected, please head over to the [SparkFun Technical Assistance](https://www.sparkfun.com/technical_assistance) page for some initial troubleshooting.
    <center>
    [SparkFun Technical Assistance Page](https://www.sparkfun.com/technical_assistance){ .md-button .md-button--primary }
    </center>
    
    If you can't find what you need there, the [SparkFun Forums](https://forum.sparkfun.com/index.php) is a great place to search product forums and ask questions.
    
    !!! info "Account Registration Required"
        If this is your first visit to our forum, you'll need to create a [Forum Account](https://forum.sparkfun.com/ucp.php?mode=register) to search product forums and post questions.

## Discrepancies in the Documentation

All of this documentation can be modified by you! Please help us make it better.

* The documentation files for these pages are contained in the [`docs` folder](https://github.com/sparkfun/SparkFun_Thing_Plus_ESP32-S3/tree/main/docs) of the [SparkFun Thing Plus - ESP32-S3](https://github.com/sparkfun/SparkFun_Thing_Plus_ESP32-S3) repository.

### Spot something wrong?
If a section of the documentation is incorrect, please [open an issue](https://github.com/sparkfun/SparkFun_Thing_Plus_ESP32-S3/issues) and let us know.

### Do you have a suggested correction?
1. With a GitHub account, fork this repo
2. Add your correction(s) or improvement(s) to the markdown file(s)
3. File a pull request with your changes, and enjoy making the ~~words~~ ~~worlds~~ world a better place.
	* Once received, the documentation specialist will automatically be notified.
	* We will review your suggested improvement(s) to make sure they are correct and fit within our documentation standards.

## Problems in the Hardware Design

All of our designs are open-source! Please help us make it better.

* Our board design files are contained in the [`Hardware` folder](https://github.com/sparkfun/SparkFun_Thing_Plus_ESP32-S3/tree/main/Hardware) of the [SparkFun Thing Plus - ESP32-S3](https://github.com/sparkfun/SparkFun_Thing_Plus_ESP32-S3) repository.

### Does something not make sense?
If part of the design is confusing, please [open an issue](https://github.com/sparkfun/SparkFun_Thing_Plus_ESP32-S3/issues) and let us know.

### Did we forget to include an important function of the board?
* Please keep in mind that we may intentionally exclude certain functions of the board to meet our product design requirements. *(For example, our Qwiic Micro boards are intended to fit on a small board layout and only use I<sup>2</sup>C communication; therefore, we may not have the SPI and interrupt pins available for users.)*
* If part of the board's functionality is missing, please [open an issue](https://github.com/sparkfun/SparkFun_Thing_Plus_ESP32-S3/issues) and file a feature request.

### Do you wish to contribute directly to improving the board design?
1. With a GitHub account, Fork this repo
2. Add your design improvement(s)
3. File a pull request with your changes, and enjoy making the ~~words~~ ~~worlds~~ world a better place.
	* Once received, the engineer in charge of the original design will automatically be notified.
	* We will review your suggested improvement(s), if they are within our board design standards and meet our product design requirements, we will flag these changes for our next board revision. *(Please note, that even if your suggestion is accepted, these changes may not be immediate. We may have to cycle through our current product inventory first.)*

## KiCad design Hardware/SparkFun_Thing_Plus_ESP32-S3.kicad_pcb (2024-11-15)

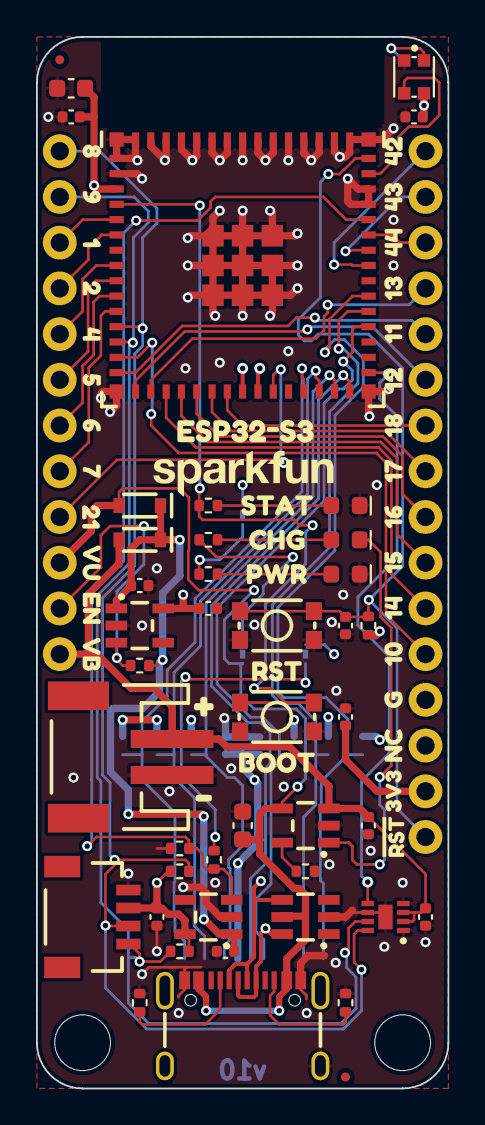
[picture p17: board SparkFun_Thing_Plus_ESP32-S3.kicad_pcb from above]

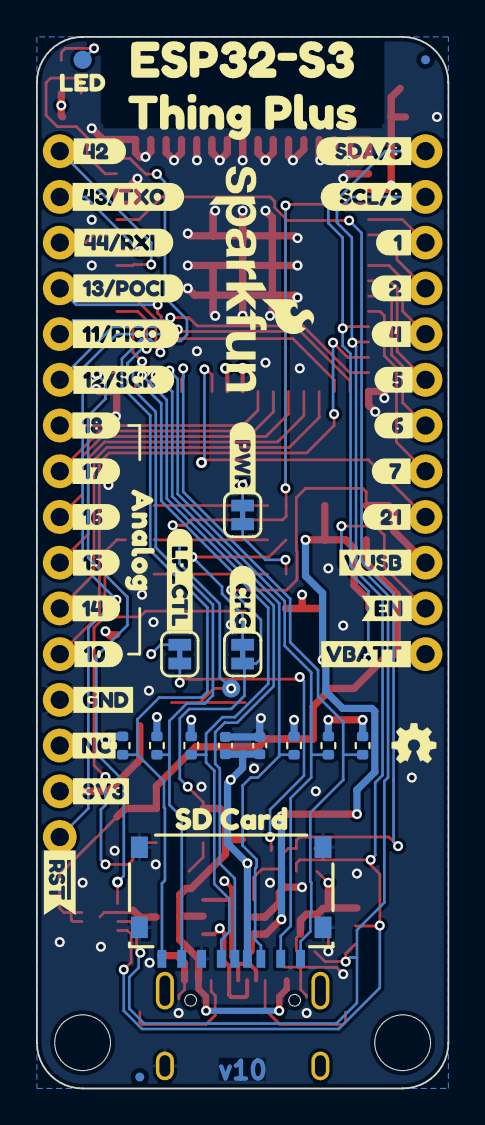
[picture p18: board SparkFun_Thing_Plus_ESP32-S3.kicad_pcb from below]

Board: 4 copper layers, 22.9 x 58.4 mm, 137 parts (53 on the bottom side), 53 nets.

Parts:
C1: 22uF; C_0603_1608Metric
C2, C5, C8, C11: 0.1uF; C_0402_1005Metric
C3, C4: 10uF; C_0402_1005Metric
C6, C13: 1.0uF; C_0402_1005Metric
C7, C12: 4.7uF; C_0402_1005Metric
C9: 4.7uF; C_0603_1608Metric
C10, C14: 2.2uF; C_0402_1005Metric
D1: Green; LED_0603_1608Metric_Green
D2, D3: BAT60A; SOD-323
D4: Yellow; LED_0603_1608Metric_Yellow
D5: Red; LED_0603_1608Metric_Red
D6: WS2812B; WS2812_2020
FID1, FID2, FID3, FID4: Fiducial_0.5mm; Fiducial_0.5mm_Mask1mm
G3: OSHW_Logo; Creative_Commons_License
J1: USB_C_Receptacle; USB-C_16
J2: microSD_Friction; microSD_Friction_Fit_Common
J3: JST_2mm_LiPo; JST_SMD_2.0mm-2
J4: Qwiic_RA; JST_SMD_1.0mm-4_RA
JP1, JP2, JP3: Jumper_2_NC_Trace
R1, R2, R3, R4, R5, R6, R8, R17: 10k; R_0402_1005Metric
R7: 330; R_0402_1005Metric
R9: 4.7k; R_0402_1005Metric
R10, R11: 5.1k; R_0402_1005Metric
R12, R15: 2.2k; R_0402_1005Metric
R13, R19: 100k; R_0402_1005Metric
R14: 1k; R_0402_1005Metric
R16: 2.0k; R_0402_1005Metric
Ref**: Val**; OSHW_Logo_2.5mm
ST1, ST3: Standoff
SW1, SW2: SMD_4.6x2.8mm_h2.5mm; Push_SMD_4.6x2.8mm_h2.5mm
TP1, TP2: 1.0mm; TestPoint-1.0mm
U1, U6: RT9080-3.3; SOT23-5
U2: DT1042-04SO; SOT23-6
U3: ESP32-S3-MINI; ESP32-MINI
U4: MAX17048; DFN-8
U5: MCP73831; SOT23-5
U9: Ordering_Instructions
U10: ThingPlus
kibuzzard-65A99A9C: G***; kibuzzard-65A99A9C
kibuzzard-65A99AA3: G***; kibuzzard-65A99AA3
kibuzzard-65A99E72: G***; kibuzzard-65A99E72
kibuzzard-65A403E0: G***; kibuzzard-65A403E0
kibuzzard-65A992E3: G***; kibuzzard-65A992E3
kibuzzard-65A9923A: G***; kibuzzard-65A9923A
kibuzzard-65A9926C: G***; kibuzzard-65A9926C
kibuzzard-65A9926F: G***; kibuzzard-65A9926F
kibuzzard-65A9927C: G***; kibuzzard-65A9927C
kibuzzard-65A9927F: G***; kibuzzard-65A9927F
kibuzzard-65A9928A: G***; kibuzzard-65A9928A
kibuzzard-65A9928E: G***; kibuzzard-65A9928E
kibuzzard-65A9933C: G***; kibuzzard-65A9933C
kibuzzard-65A9934B: G***; kibuzzard-65A9934B
kibuzzard-65A9935C: G***; kibuzzard-65A9935C
kibuzzard-65A9936B: G***; kibuzzard-65A9936B
kibuzzard-65A9990D: G***; kibuzzard-65A9990D
kibuzzard-65A99252: G***; kibuzzard-65A99252
kibuzzard-65A99268: G***; kibuzzard-65A99268
kibuzzard-65A99274: G***; kibuzzard-65A99274
kibuzzard-65A99278: G***; kibuzzard-65A99278
kibuzzard-65A99283: G***; kibuzzard-65A99283
kibuzzard-65A99287: G***; kibuzzard-65A99287
kibuzzard-65A99292: G***; kibuzzard-65A99292
kibuzzard-65A99297: G***; kibuzzard-65A99297
kibuzzard-65A99335: G***; kibuzzard-65A99335
kibuzzard-65A99346: G***; kibuzzard-65A99346
kibuzzard-65A99350: G***; kibuzzard-65A99350
kibuzzard-65A99354: G***; kibuzzard-65A99354
kibuzzard-65A99359: G***; kibuzzard-65A99359
kibuzzard-65A99360: G***; kibuzzard-65A99360
kibuzzard-65A99364: G***; kibuzzard-65A99364
kibuzzard-65A99367: G***; kibuzzard-65A99367
kibuzzard-65A99912: G***; kibuzzard-65A99912
kibuzzard-65A99933: G***; kibuzzard-65A99933
kibuzzard-65AA9C9F: G***; kibuzzard-65AA9C9F
kibuzzard-656A3D93: G***; kibuzzard-656A3D93
kibuzzard-656A31AF: G***; kibuzzard-656A31AF
kibuzzard-656A32A0: G***; kibuzzard-656A32A0
kibuzzard-656A32FE: G***; kibuzzard-656A32FE
kibuzzard-656A35A5: G***; kibuzzard-656A35A5
kibuzzard-656A35AD: G***; kibuzzard-656A35AD
kibuzzard-656A35B5: G***; kibuzzard-656A35B5
kibuzzard-656A35BC: G***; kibuzzard-656A35BC
kibuzzard-656A35C4: G***; kibuzzard-656A35C4
kibuzzard-656A36A2: G***; kibuzzard-656A36A2
kibuzzard-656A36A7: G***; kibuzzard-656A36A7
kibuzzard-656A36C2: G***; kibuzzard-656A36C2
kibuzzard-656A47C5: G***; kibuzzard-656A47C5
kibuzzard-656A359E: G***; kibuzzard-656A359E
kibuzzard-656A361F: G***; kibuzzard-656A361F
kibuzzard-656A367B: G***; kibuzzard-656A367B
kibuzzard-656A368C: G***; kibuzzard-656A368C
kibuzzard-656A482A: G***; kibuzzard-656A482A
kibuzzard-656A3526: G***; kibuzzard-656A3526
kibuzzard-656A3552: G***; kibuzzard-656A3552
kibuzzard-656A3559: G***; kibuzzard-656A3559
kibuzzard-656A3560: G***; kibuzzard-656A3560
kibuzzard-656A3567: G***; kibuzzard-656A3567
kibuzzard-656A3591: G***; kibuzzard-656A3591
kibuzzard-656A3598: G***; kibuzzard-656A3598
kibuzzard-656A3668: G***; kibuzzard-656A3668
kibuzzard-656A3687: G***; kibuzzard-656A3687
kibuzzard-656A3691: G***; kibuzzard-656A3691
kibuzzard-656A3878: G***; kibuzzard-656A3878
kibuzzard-656A4896: G***; kibuzzard-656A4896
kibuzzard-6569BE4A: G***; kibuzzard-6569BE4A
kibuzzard-6569BE28: G***; kibuzzard-6569BE28
kibuzzard-6569BE57: G***; kibuzzard-6569BE57
kibuzzard-6569BF02: G***; kibuzzard-6569BF02
kibuzzard-6569F7FC: G***; kibuzzard-6569F7FC
kibuzzard-6569F8A4: G***; kibuzzard-6569F8A4

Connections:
3.3V: C1.2, C7.1, C11.1, C13.1, JP1.2 (B), JP2.2 (B), R8.1, U3.3 (3V3), U6.5 (VOUT), U10.27 (3.3V)
3.3V_P: C3.1, C4.1, C5.1, C8.1, D6.4 (VDD), J2.4 (VDD), J4.2, R1.1, R2.1, R3.1, R4.1, R5.1, R6.1, R12.1, R15.1, U1.5 (VOUT)
EN: R13.2, U6.3 (EN), U10.11 (EN)
ESP0/STAT: R7.1, SW1.1, TP2.1, U3.4 (IO0)
ESP1: U3.5 (IOA1), U10.3 (GPIO6)
ESP2: U3.6 (IOA2), U10.4 (GPIO5)
ESP4: U3.8 (IOA4), U10.5 (GPIO4)
ESP5: U3.9 (IOA5), U10.6 (GPIO3)
ESP6: U3.10 (IOA6), U10.7 (GPIO2)
ESP7: U3.11 (IOA7), U10.8 (GPIO1)
ESP8/SDA: J4.3, R15.2, U3.12 (IOA8), U4.8 (SDA), U10.1 (SDA)
ESP9/SCL: J4.4, R12.2, U3.13 (IOA9), U4.7 (SCL), U10.2 (SCL)
ESP10/A0: U3.14 (IOA10), U10.24 (A0)
ESP11/PICO: U3.15 (IOA11), U10.17 (PICO)
ESP12/SCK: U3.16 (IOA12), U10.18 (SCK)
ESP13/POCI: U3.17 (IOA13), U10.16 (POCI)
ESP14/A1: U3.18 (IOA14), U10.23 (A1)
ESP15/A2: U3.19 (IOA15), U10.22 (A2)
ESP16/A3: U3.20 (IOA16), U10.21 (A3)
ESP17/A4: U3.21 (IOA17), U10.20 (A4)
ESP18/A5: U3.22 (IOA18), U10.19 (A5)
ESP19/D-: J1.A7 (D-), J1.B7 (D-), U2.4 (I/O3), U3.23 (IOA19)
ESP20/D+: J1.A6 (D+), J1.B6 (D+), U2.6 (I/O4), U3.24 (IOA20)
ESP21: U3.25 (IO21), U10.9 (GPIO0)
ESP33/SDIO3: J2.2 (DAT3/~CS), R6.2, U3.28 (IO33)
ESP34/SDIO_CMD: J2.3 (CMD/SDI), R1.2, U3.29 (IO34)
ESP35/~ALRT: U3.31 (IO35), U4.5 (~ALRT)
ESP38/SDIO_CLK: J2.5 (CLK/SCK), R2.2, U3.34 (IO38)
ESP39/SDIO0: J2.7 (DAT0/SDO), R3.2, U3.35 (IO39)
ESP40/SDIO1: J2.8 (DAT1), R4.2, U3.36 (IO40)
ESP42/FREE: U3.38 (IO42), U10.13 (FREEBIE)
ESP43/TXO: U3.39 (TXD0/IO43), U10.14 (TX)
ESP44/RXI: U3.40 (RXD0/IO44), U10.15 (RX)
ESP45/Q_EN: R17.2, R19.1, U1.3 (EN), U3.41 (IO45)
ESP46/LED: D6.3 (DIN), U3.44 (IO46)
ESP47/SDIO2: J2.1 (DAT2), R5.2, U3.27 (IO47)
ESP48/SDIO_~DET: J2.9 (DET), U3.30 (IO48)
ESP~RST: C6.1, R8.2, SW2.1, U3.45 (EN), U10.28 (~RESET)
GND: C1.1, C2.2, C3.2, C4.2, C5.2, C6.2, C7.2, C8.2, C9.2, C10.2, C11.2, C12.2, C13.2, C14.2, D1.1 (K), D5.1 (K), D6.2 (VSS), J1.GND, J1.S (SHIELD), J2.6 (VSS), J2.10 (SHIELD), J3.1 (-), J4.1, R10.1, R11.2, R16.2, R19.2, SW1.2, SW2.2, U1.2 (GND), U2.2 (GND), U3.1 (GND), U3.2 (GND), U3.42 (GND), U3.43 (GND), U3.46 (GND), U3.47 (GND), U3.48 (GND), U3.49 (GND), U3.50 (GND), U3.51 (GND), U3.52 (GND), U3.53 (GND), U3.54 (GND), U3.55 (GND), U3.56 (GND), U3.57 (GND), U3.58 (GND), U3.59 (GND), U3.60 (GND), U3.61 (GND), U3.62 (GND), U3.63 (GND), U3.64 (GND), U3.65 (GND), U4.1 (CTG), U4.4 (GND), U4.6 (QSTRT), U4.9 (GND), U5.2 (GND), U6.2 (GND), U10.25 (GND)
unnamed: D1.2 (A), R7.2
unnamed: D4.2 (A), R14.1
unnamed: D4.1 (K), U5.1 (STAT)
unnamed: D5.2 (A), R9.2
unnamed: D6.1 (DOUT), TP1.1
unnamed: J1.A5 (CC1), R11.1
unnamed: J1.B5 (CC2), R10.2
unnamed: JP1.1 (A), R9.1
unnamed: JP2.1 (A), R17.1
unnamed: JP3.1 (A), R14.2
unnamed: R16.1, U5.5 (PROG)
VBATT: C2.1, C12.1, D3.A, J3.2 (+), U4.2 (CELL), U4.3 (VDD), U5.3 (V_{BAT}), U10.12 (V_BATT)
VIN: C10.1, C14.1, D2.C, D3.C, R13.1, U1.1 (VIN), U6.1 (VIN)
VUSB: C9.1, D2.A, J1.VBUS, JP3.2 (B), U2.5 (VCC), U5.4 (VIN), U10.10 (V_USB)

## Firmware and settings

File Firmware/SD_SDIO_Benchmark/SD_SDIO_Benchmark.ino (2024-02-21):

/*
  Use the built-in ESP32 SD_MMC library to test the SD write speed over 4-bit SDIO.
  By: Nathan Seidle
  SparkFun Electronics
  Date: January 13, 2024
  License: MIT. Please see LICENSE.md for more information.

  This demonstrates 4-bit SDIO write and read speed averages. We found
  2.5MB/s to ~4.1MB/s on various microSD cards 1GB to 32GB.

  These exmaples are written not to demonstrate the absolute extremes that a library
  may be capable. Instead, we try to emulate normal user experiences, with basic read/writes.

  Shockingly, sdFat performed as fast, or faster than the SDIO 4-bit interface in many circumstances.

  Tested using ESP32 core v2.0.14

  Feel like supporting open source hardware?
  Buy a board from SparkFun!
  SparkFun ESP32-S3 Thing Plus (DEV-24408) https://www.sparkfun.com/products/24408

  Select the following in the Arduino IDE:
  Board: ESP32S3 Dev Module
  USB Mode: Hardware CDC and JTAG
  USB CDC on Boot: Enabled
  Upload Mode: UART0 / Hardware CDC
  PSRAM: QSPI PSRAM
  Port: Select the COM port that the device shows up on under device manager
*/

#include "FS.h"
#include "SD_MMC.h"

//Define pins for SDIO interface
int pin_sdioCLK = 38;
int pin_sdioCMD = 34;
int pin_sdioD0 = 39;
int pin_sdioD1 = 40;
int pin_sdioD2 = 47;
int pin_sdioD3 = 33;

void setup()
{
  Serial.begin(115200);
  while (Serial == false);
  Serial.println();
  Serial.println("SDIO test");

  runTestsSDIO();
}

void loop()
{
  if (Serial.available()) ESP.restart();
}

void runTestsSDIO()
{
  //Define pin interface to SDIO card
  if (SD_MMC.setPins(pin_sdioCLK, pin_sdioCMD, pin_sdioD0, pin_sdioD1, pin_sdioD2, pin_sdioD3) == false)
  {
    Serial.println("SDIO pin assignment failed!");
    return;
  }

  if (SD_MMC.begin() == false)
  {
    Serial.println("Card Mount Failed");
    return;
  }

  uint8_t cardType = SD_MMC.cardType();
  if (cardType == CARD_NONE)
  {
    Serial.println("No SD_MMC card detected");
    return;
  }

  Serial.print("SD_MMC Card Type: ");
  if (cardType == CARD_MMC)
    Serial.println("MMC");
  else if (cardType == CARD_SD)
    Serial.println("SDSC");
  else if (cardType == CARD_SDHC)
    Serial.println("SDHC");
  else
    Serial.println("UNKNOWN");

  Serial.printf("Card Size: %lluMB\n", SD_MMC.cardSize() / (1024 * 1024));
  Serial.printf("Total space: %lluMB\n", SD_MMC.totalBytes() / (1024 * 1024));
  Serial.printf("Used space: %lluMB\n", SD_MMC.usedBytes() / (1024 * 1024));

  float avgWriteSpeed = 0.0;
  float avgReadSpeed = 0.0;
  int avgAmount = 10;

  for (int i = 0 ; i < avgAmount ; i++)
  {
    //10k and 100k report very slow writes
    avgWriteSpeed += fileWriteTest("/test.txt", 500000); //500k is a little slower but mostly indicative of 5MB
    avgReadSpeed += fileReadTest("/test.txt");
  }
  avgWriteSpeed /= avgAmount;
  avgReadSpeed /= avgAmount;

  Serial.printf("avgWriteSpeed: %0.2f avgReadSpeed: %0.2f", avgWriteSpeed, avgReadSpeed);
}

float fileWriteTest(const char *path, uint32_t bytesToWrite)
{
  static uint8_t buf[512];

  //Remove test file if it exists
  SD_MMC.remove(path);

  File file = SD_MMC.open(path, FILE_WRITE);
  if (!file)
  {
    Serial.println("Failed to open file for writing");
    return (0.0);
  }

  randomSeed(micros());

  //Fill buffer with random bytes
  for (int x = 0 ; x < sizeof(buf) ; x++)
    buf[x] = random(0, 256); //Inclusive, exclusive

  unsigned long startTime = millis();
  uint32_t bytesLeftToWrite = bytesToWrite;

  while (bytesLeftToWrite > 0)
  {
    uint16_t bytesWritten = 512;
    if (bytesWritten > bytesLeftToWrite)
      bytesWritten = bytesLeftToWrite;
    bytesWritten = file.write(buf, bytesWritten);
    bytesLeftToWrite -= bytesWritten;
  }

  unsigned long writeTime = millis() - startTime;

  float writeSpeed = bytesToWrite / 1000000. / (writeTime / 1000.);

  Serial.printf("Write Test: %0.2f MB = %0.2f MB/s ", bytesToWrite / 1000000., writeSpeed);

  file.close();

  return (writeSpeed);
}

//Read a given file and print the time taken as well as MB/s
float fileReadTest(const char * path)
{
  File file = SD_MMC.open(path);
  if (!file)
  {
    Serial.println("Failed to open file for reading");
    return (0.0);
  }

  unsigned long bytesLeftToRead = file.size();
  unsigned long fileSize = bytesLeftToRead;
  static uint8_t buf[512];

  unsigned long startTime = millis();
  while (bytesLeftToRead > 0)
  {
    size_t toRead = bytesLeftToRead;
    if (toRead > 512)
      toRead = 512;
    file.read(buf, toRead);
    bytesLeftToRead -= toRead;
  }

  unsigned long readTime = millis() - startTime;

  float readSpeed = fileSize / 1000000. / (readTime / 1000.);
  Serial.printf("Read Test: %0.2f MB = %0.2f MB/s\r\n", fileSize / 1000000., readSpeed);

  file.close();

  return (readSpeed);
}

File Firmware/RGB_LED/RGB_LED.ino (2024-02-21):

/*
  Control Addressable RGB LED
  By: Nathan Seidle
  SparkFun Electronics
  Date: January 13, 2024
  License: MIT. Please see LICENSE.md for more information.

  This example shows how to illuminate the RGB on the SparkFun ESP32 S3 Thing Plus.

  Feel like supporting open source hardware?
  Buy a board from SparkFun!
  SparkFun ESP32-S3 Thing Plus (DEV-24408) https://www.sparkfun.com/products/24408

  Select the following in the Arduino IDE:
  Board: ESP32S3 Dev Module
  USB Mode: Hardware CDC and JTAG
  USB CDC on Boot: Enabled
  Upload Mode: UART0 / Hardware CDC
  PSRAM: QSPI PSRAM
  Port: Select the COM port that the device shows up on under device manager
*/

#include <FastLED.h> // http://librarymanager/All#FastLED

#define LED_PIN     46 //Pin 46 on Thing Plus C S3 is connected to WS2812 LED
#define COLOR_ORDER GRB
#define CHIPSET     WS2812
#define NUM_LEDS    1

#define BRIGHTNESS  25

CRGB leds[NUM_LEDS];

void setup()
{
  Serial.begin(115200);
  //while (Serial == false); //Wait for serial monitor to connect before printing anything

  FastLED.addLeds<CHIPSET, LED_PIN, COLOR_ORDER>(leds, NUM_LEDS).setCorrection(TypicalLEDStrip);
  FastLED.setBrightness(BRIGHTNESS);
}

void loop()
{
  leds[0] = CRGB::Red;
  FastLED.show();
  delay(200);

  leds[0] = CRGB::Green;
  FastLED.show();
  delay(200);

  leds[0] = CRGB::Blue;
  FastLED.show();
  delay(200);

  leds[0] = CRGB::Black;
  FastLED.show();
  delay(100);

  leds[0] = CRGB::White;
  FastLED.show();
  delay(2000);

  leds[0] = CRGB::Black;
  FastLED.show();
  delay(100);
}

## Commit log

2024-01-15 Remove single unit production files
    [SparkFun_Thing_Plus_ESP32-S3.GBL, SparkFun_Thing_Plus_ESP32-S3.GBO, SparkFun_Thing_Plus_ESP32-S3.GBP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]
2024-01-15 Update rev number
    [SparkFun_Thing_Plus_ESP32-S3.kicad_sch, SparkFun_Thing_Plus_ESP32-S3_Peripherals.kicad_sch]
2024-01-18 Updates post review
    [SparkFun_Thing_Plus_ESP32-S3.kicad_pcb, SparkFun_Thing_Plus_ESP32-S3.kicad_sch, SparkFun_Thing_Plus_ESP32-S3_Peripherals.kicad_sch]
2024-01-19 Add default on to Qwiic power.
    [SparkFun_Thing_Plus_ESP32-S3.kicad_pcb, SparkFun_Thing_Plus_ESP32-S3.kicad_sch, SparkFun_Thing_Plus_ESP32-S3_Peripherals.kicad_sch]
2024-02-15 Revise layout post design review
    [SparkFun_Thing_Plus_ESP32-S3.kicad_pcb, SparkFun_Thing_Plus_ESP32-S3.kicad_sch, SparkFun_Thing_Plus_ESP32-S3_Peripherals.kicad_sch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]
2024-02-16 Fix 330 prod ID. Update parts to new naming conventions
    [SparkFun_Thing_Plus_ESP32-S3.kicad_pcb, SparkFun_Thing_Plus_ESP32-S3.kicad_sch, SparkFun_Thing_Plus_ESP32-S3_Peripherals.kicad_sch]
2024-02-23 Docs update
    Updating Arduino examples w/more detail & info on esptool upload errors.
2024-02-27 Docs Update
    Adding board files/assets and updating relevant sections. Prepping examples section for release.
2024-11-15 Update with current models and symbols
    [SparkFun_Thing_Plus_ESP32-S3.kicad_pcb, SparkFun_Thing_Plus_ESP32-S3.kicad_sch, SparkFun_Thing_Plus_ESP32-S3_Peripherals.kicad_sch]

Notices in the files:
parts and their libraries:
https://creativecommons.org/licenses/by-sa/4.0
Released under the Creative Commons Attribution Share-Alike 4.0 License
